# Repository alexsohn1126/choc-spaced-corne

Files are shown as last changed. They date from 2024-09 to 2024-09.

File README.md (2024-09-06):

# choc-spaced-corne
Choc spaced corne based on klouderone's [cornev4promicroedition](https://github.com/klouderone/cornev4promicroedition)

Does not feature hotswap and TRRS plugs.

Pinouts are the same as the classic corne, so the firmware setup is as simple as choosing corne in [zmk setup](https://zmk.dev/docs/user-setup).

## Images
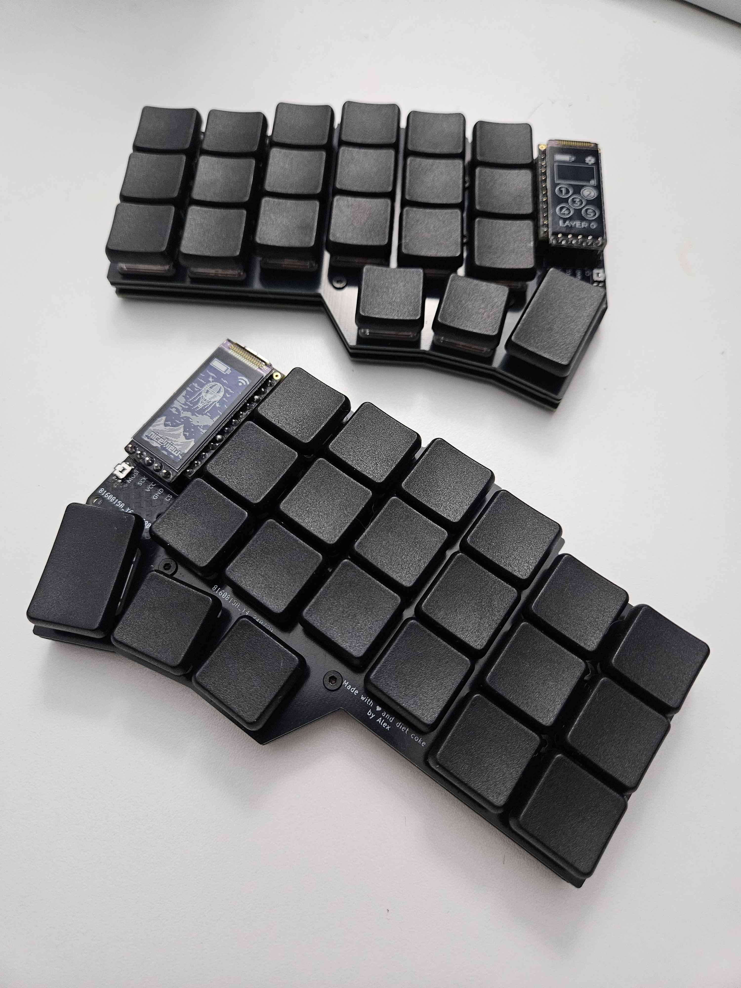
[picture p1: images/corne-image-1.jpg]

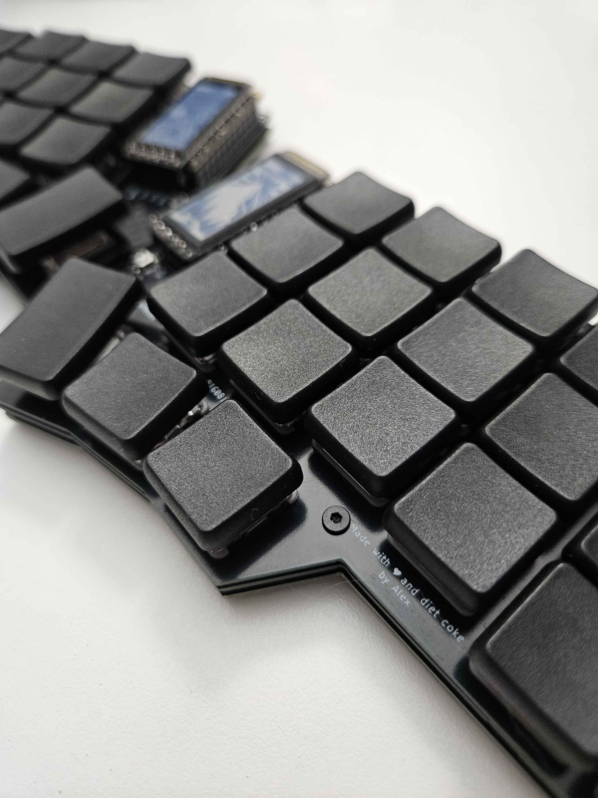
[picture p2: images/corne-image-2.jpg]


## Materials Used & Costs
| Material | Cost |
|---|---|
| [Choc v1 pink switches 50 pcs](https://www.aliexpress.us/item/3256804880270570.html) | ~30 USD |
| [100pcs SMD diodes](https://www.aliexpress.us/item/3256803008359866.html) | ~1 USD  |
| [100pcs silicone feet](https://www.aliexpress.us/item/3256802433629049.html) | ~1 USD  |
| [Black choc keycaps 50pcs + 2 of 1.5u keycap](https://www.boardsource.xyz/products/MBK_blanks) | ~20 USD |
| 2 of [SuperMini NRF52840](https://www.aliexpress.us/item/3256805848952479.html) | ~10 USD |
| [10pcs 301230 batteries](https://www.aliexpress.us/item/3256806816440012.html) | ~8 USD  |
| 5mm version of [copper m2 copper pillar](https://www.aliexpress.us/item/3256804637215652.html) | ~3 USD  |
| 4mm version of [m2 screws](https://www.aliexpress.us/item/3256804698330962.html) | ~1 USD  |
| 2 of [nice!view](https://typeractive.xyz/products/nice-view) | ~40 USD |
| 2 of [PCM12SMTR](https://www.digikey.com/en/products/detail/c-k/pcm12smtr/1640112) | ~3 USD  |
| 2 of [EVQ-P7A01P](https://www.digikey.com/en/products/detail/panasonic-electronic-components/evq-p7a01p/4429447) | ~1 USD  |
| pcb order at jlcpcb | ~30 USD |
| Optional: [pvc washers](https://www.aliexpress.us/item/3256804190495486.html) | ~2 USD  |
| | |
| Total | 150 USD |

After I did the calculations, this isn't much cheaper than getting a kit from vendors out there after shipping, just as a warning.

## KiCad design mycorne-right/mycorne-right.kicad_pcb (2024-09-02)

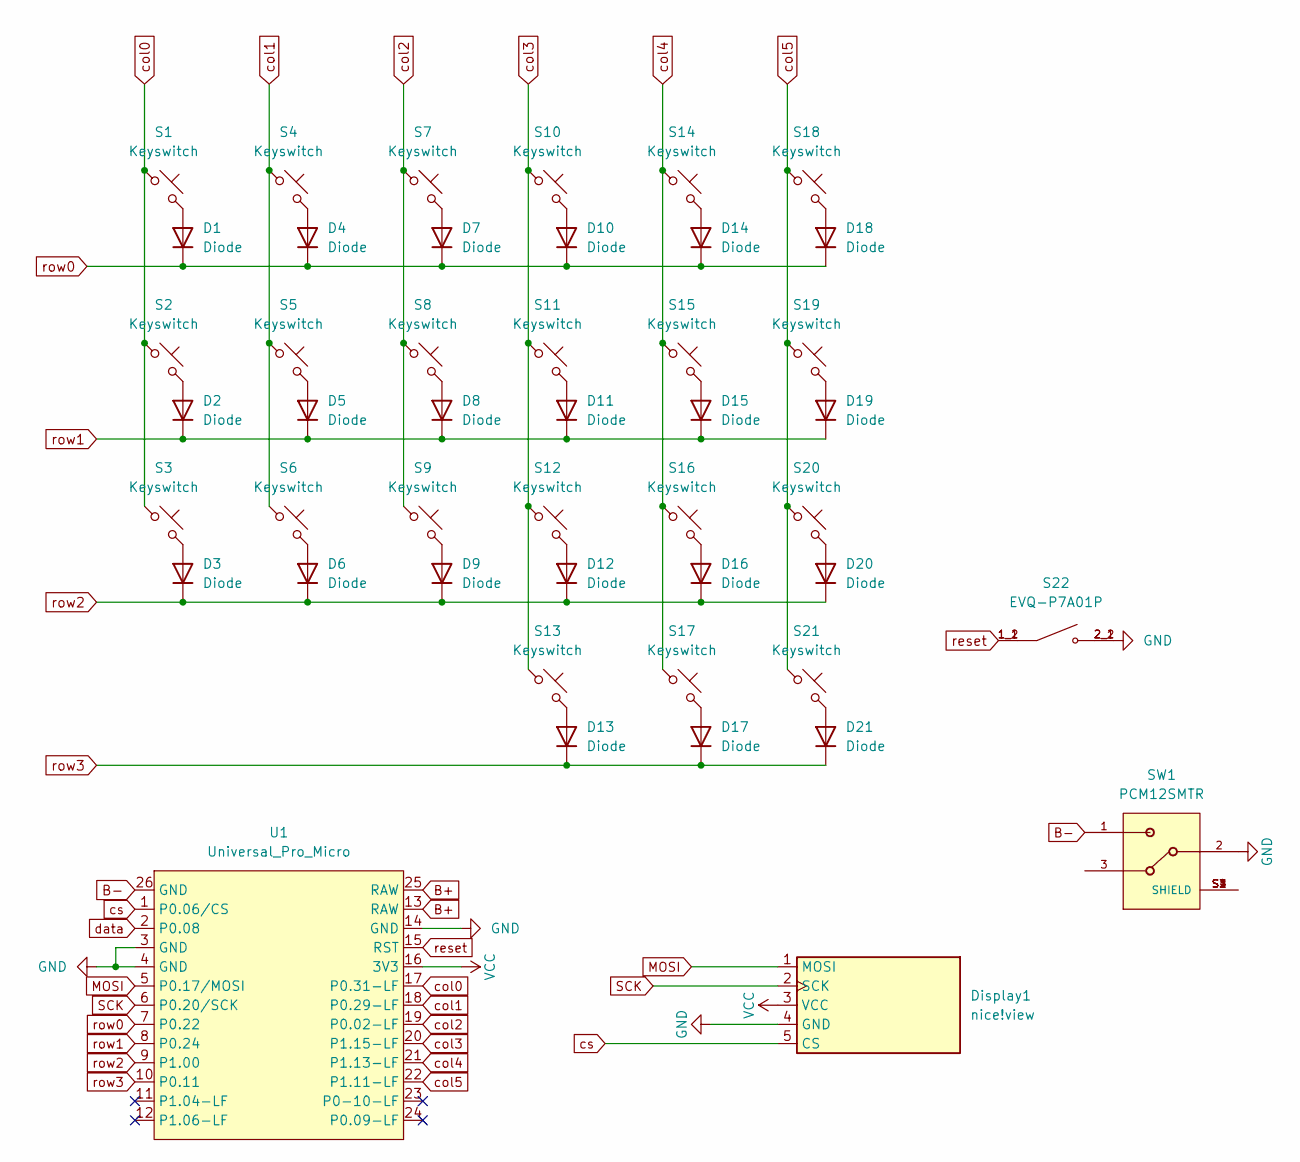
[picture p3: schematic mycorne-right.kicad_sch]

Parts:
D1, D2, D3, D4, D5, D6, D7, D8, D9, D10, D11, D12, D13, D14, D15, D16, D17, D18, D19, D20, D21: Diode; Diode_SOD-123
Display1: nice!view; nice_view
S1, S2, S3, S4, S5, S6, S7, S8, S9, S10, S11, S12, S13, S14, S15, S16, S17, S18, S19, S20: Keyswitch; Choc_V1_1.00u
S21: Keyswitch; Choc_V1_1.50u
S22: EVQ-P7A01P; SW_EVQ-P7A01P; PARTREV 2022.4
SW1: PCM12SMTR; SW_SPDT_PCM12
U1: Universal_Pro_Micro; Universal_Pro_Micro_Footprint

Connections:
B+: U1.13 (RAW), U1.25 (RAW)
B-: SW1.1, U1.26 (GND)
GND: Display1.4 (GND), S22.2_1, S22.2_2, SW1.2, U1.3 (GND), U1.4 (GND), U1.14 (GND)
MOSI: Display1.1 (MOSI), U1.5 (P0.17/MOSI)
unnamed: D1.2 (A), S1.2
unnamed: D2.2 (A), S2.2
unnamed: D3.2 (A), S3.2
unnamed: D4.2 (A), S4.2
unnamed: D5.2 (A), S5.2
unnamed: D6.2 (A), S6.2
unnamed: D7.2 (A), S7.2
unnamed: D8.2 (A), S8.2
unnamed: D9.2 (A), S9.2
unnamed: D10.2 (A), S10.2
unnamed: D11.2 (A), S11.2
unnamed: D12.2 (A), S12.2
unnamed: D13.2 (A), S13.2
unnamed: D14.2 (A), S14.2
unnamed: D15.2 (A), S15.2
unnamed: D16.2 (A), S16.2
unnamed: D17.2 (A), S17.2
unnamed: D18.2 (A), S18.2
unnamed: D19.2 (A), S19.2
unnamed: D20.2 (A), S20.2
unnamed: D21.2 (A), S21.2
SCK: Display1.2 (SCK), U1.6 (P0.20/SCK)
VCC: Display1.3 (VCC), U1.16 (3V3)
col0: S1.1, S2.1, S3.1, U1.17 (P0.31-LF)
col1: S4.1, S5.1, S6.1, U1.18 (P0.29-LF)
col2: S7.1, S8.1, S9.1, U1.19 (P0.02-LF)
col3: S10.1, S11.1, S12.1, S13.1, U1.20 (P1.15-LF)
col4: S14.1, S15.1, S16.1, S17.1, U1.21 (P1.13-LF)
col5: S18.1, S19.1, S20.1, S21.1, U1.22 (P1.11-LF)
cs: Display1.5 (CS), U1.1 (P0.06/CS)
data: U1.2 (P0.08)
reset: S22.1_1, S22.1_2, U1.15 (RST)
row0: D1.1 (K), D4.1 (K), D7.1 (K), D10.1 (K), D14.1 (K), D18.1 (K), U1.7 (P0.22)
row1: D2.1 (K), D5.1 (K), D8.1 (K), D11.1 (K), D15.1 (K), D19.1 (K), U1.8 (P0.24)
row2: D3.1 (K), D6.1 (K), D9.1 (K), D12.1 (K), D16.1 (K), D20.1 (K), U1.9 (P1.00)
row3: D13.1 (K), D17.1 (K), D21.1 (K), U1.10 (P0.11)

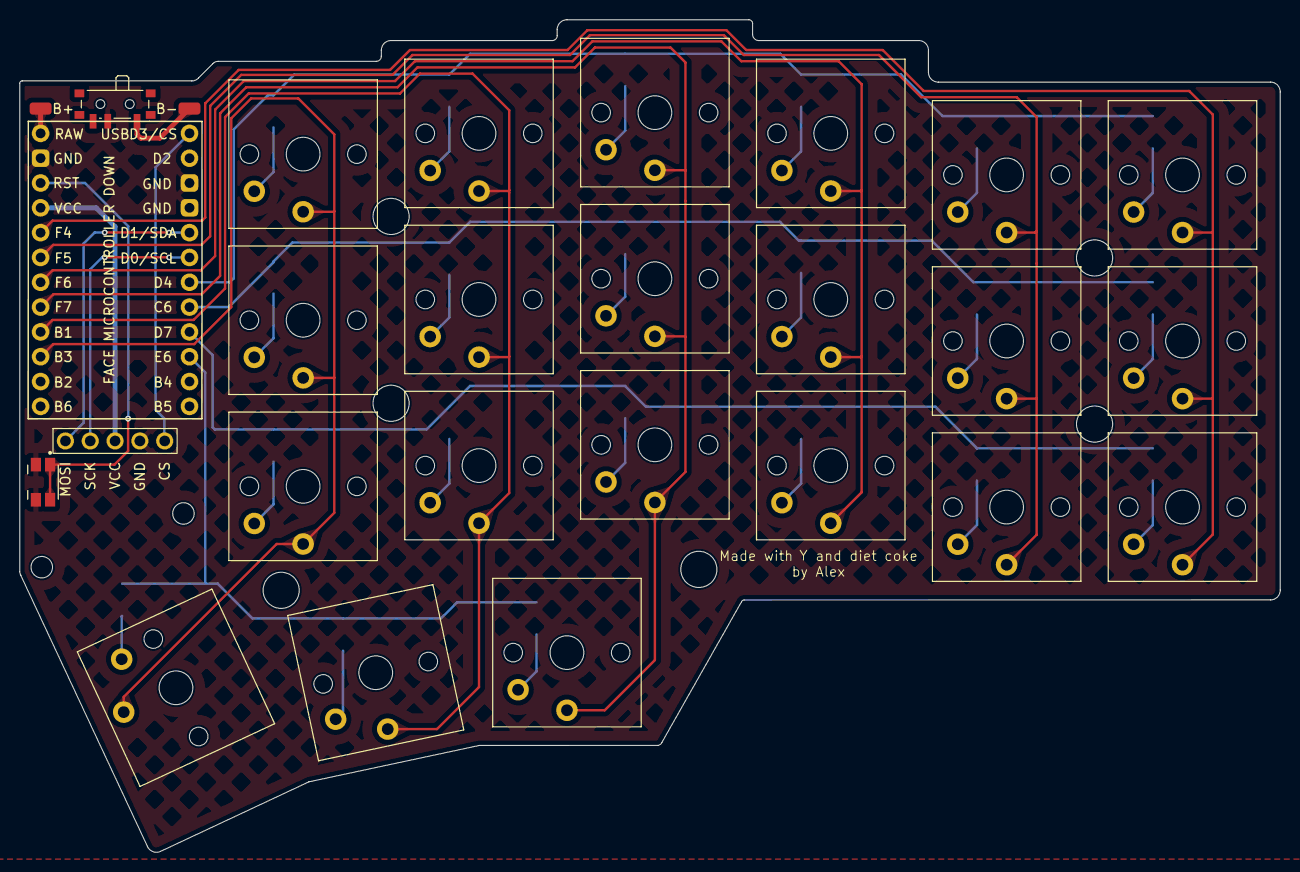
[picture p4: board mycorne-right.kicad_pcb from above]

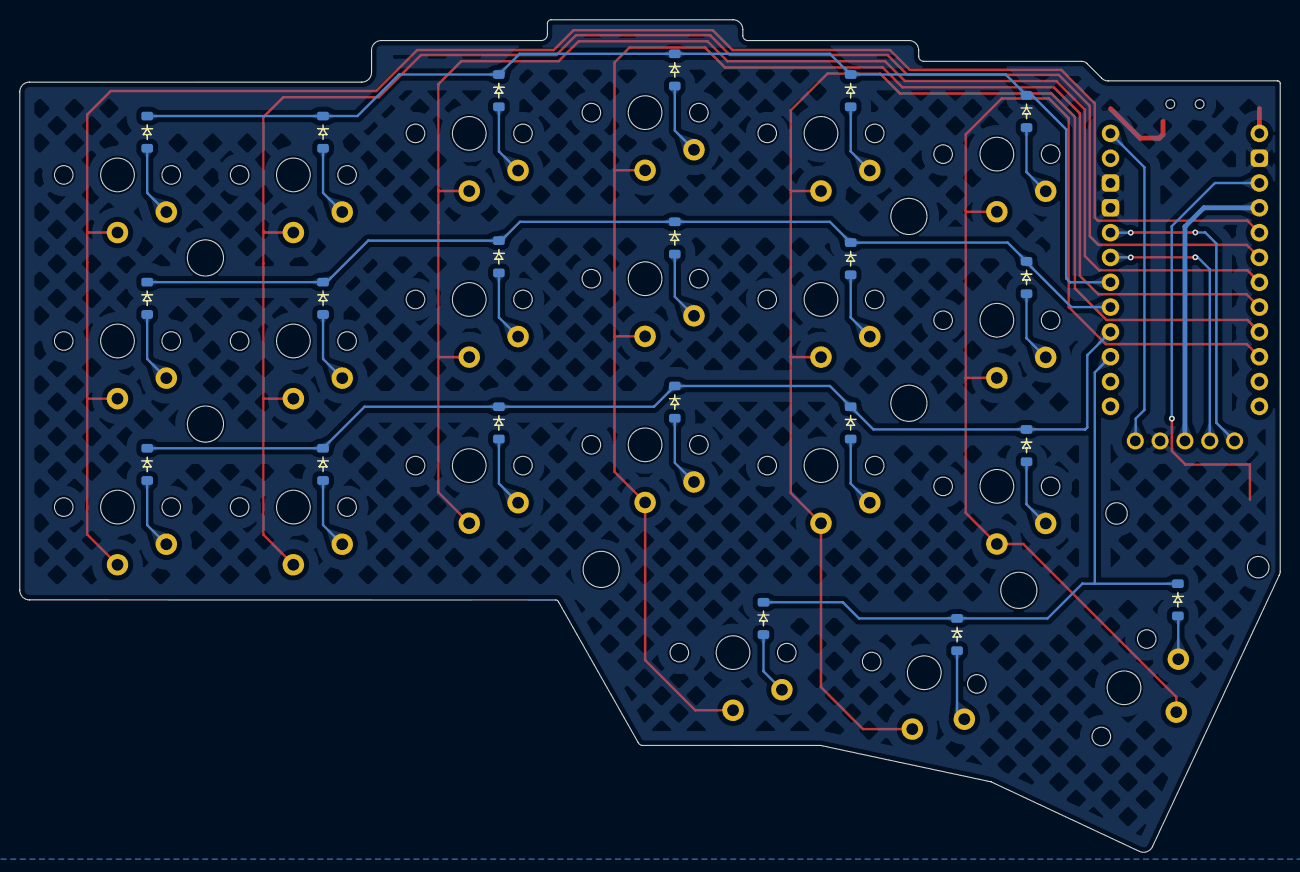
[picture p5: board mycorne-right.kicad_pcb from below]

Board: 2 copper layers, 129.0 x 85.2 mm, 46 parts (21 on the bottom side), 39 nets.

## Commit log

2024-09-02 added pcb files to the repo
    [mycorne-left.kicad_pcb, mycorne-left.kicad_sch, mycorne-right-bottom.kicad_pcb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]
2024-09-06 Add materials costs to the readme
